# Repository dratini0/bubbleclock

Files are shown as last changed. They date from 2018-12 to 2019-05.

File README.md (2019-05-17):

# LED bubble display

This project is an ESP8266-based multiplexed driver for an 14 digit LED bubble display I have found somewhere.
It uses a separate battery charging and protection circuit, but has an internal LDO, more than capable enough to supply the display and the micro with sufficient power.

## Roadmap

- [x] Redesign with looser tolerances
- [x] Design and print case
- [x] Solder board
- [x] Finish MicroPython firmware, or develop native
  - [ ] Fix flickering issue

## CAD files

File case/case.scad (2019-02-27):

use <MCAD/regular_shapes.scad>
use <MCAD/boxes.scad>

// helper functions
function maxvector(vectors) = [for (index = [0:1:len(vectors[0]) - 1]) max([for (vector = vectors) vector[index]])];

function dotmul(a, b) = [for (index = [0:1:len(a) - 1]) a[index] * b[index]];

module box_between(a, b) {
    translate(a) cube(b - a);
}

// configuration
$fs = 0.2;
$fa = 5;

// unit: mm
mil = 0.0254;
wall = [1.2, 1.2, 1];
long_extension = 100;
cap_split = 20;

// BMS
bms_thickness = 1.1 + 0.2;
bms_length = 27.9 + 1;
bms_width = 17.2 + 0.5;
bms_parts = 2 + 1;
bms_back_parts = 0.5 + 0.5;
bms_usb_height = 3 + 1;
bms_usb_underhang = 0.3;
bms_usb_width = 8;
bms_porch = 0.5;
// ALSO USB PORT!
// FIND SPECS

// screen
screen_pcb_thickness = 1.6 + 0.2;
screen_pcb_length = 60.8 + 2;
screen_pcb_width = 18.4 + 1;
screen_pcb_end_porch = 1.5 - 0.2;
screen_pcb_top_porch = 1.6 - 0.2;
screen_bubble_thickness = 3.3 + 0.3;
screen_right_edge_to_last_connector_center = 4.9;
screen_bottom_edge_to_connector_center = 2.18 + 0.5;
// Lasercut a 60mm*14.5mm piece of acrylic 2mm thick
screen_window_thickness = 2 + 0.2;
screen_window_lip = 1;
screen_window_bottom_porch = 3.5 - 0.2;

// connector
connector_pitch = 100 * mil;
connector_pins = 22;
connector_length = connector_pitch * connector_pins + 1;
connector_screen_center_to_driver_face = 180 * mil;
// https://hu.mouser.com/datasheet/2/418/NG_CD_644694_E2-1257639.pdf
connector_driver_center_to_screen_face = 8.7 + 92 * mil / 2;
connector_width = 2.5 + 0.5;

// driver
driver_thickness = 1.6 + 0.3;
driver_length = 57.15 + 2;
driver_width = 22.86 + 1;
driver_programming_connector_height = 4.4 + 1;
driver_programming_connector_extension = 2.5;
driver_top_component_height = 2.3 + 0.8;
// https://datasheet.lcsc.com/szlcsc/Ai-Thinker-ESP-12F-ESP8266MOD_C82891.pdf
driver_bottom_component_height = 2.7;
// http://www.ti.com/lit/ds/symlink/sn74hc595.pdf
driver_front_porch = 0.6;
// protrusion for switch, maybe add lever?
driver_back_top_porch = -1;
driver_back_bottom_porch = 0.5;
driver_right_edge_to_last_connector_center = 1.9;
driver_front_edge_to_connector_center = 1.9 + 0.5;
driver_switch_hole_position = 3 - 1;
driver_switch_hole_length = 4 + 2;
driver_switch_hole_width = 2;

// battery (standard 18650)
battery_dia = 18 + 1;
battery_len = 65 + 5;

// screw hole
screw_hole_dia = 5 + 1; // M3
screw_nut_dia = 9.2 + 0.2;
screw_nut_height = 4;
screw_hole_pos = [screw_nut_dia / 2 * cos(30), 11, 0];

// sample
sample_height = 15;
sample_thickness = 3;

module battery(){
    translate([battery_dia / 2, battery_dia / 2])
    cylinder(h = battery_len, d = battery_dia);
}

battery = [battery_dia, battery_dia, battery_len];

//battery();

module driver() {
    translate([0, - driver_front_edge_to_connector_center, -driver_right_edge_to_last_connector_center]) {
        // PCB
        translate([-driver_thickness, 0, 0])
        cube([driver_thickness, driver_width, driver_length]);
        // front componets
        translate([0, driver_front_porch, -driver_programming_connector_extension])
        cube([driver_programming_connector_height, driver_width - driver_front_porch - driver_back_top_porch, driver_length + driver_programming_connector_extension]);
        // back components
        translate([- driver_thickness - driver_bottom_component_height, driver_front_porch, 0])
        cube([driver_bottom_component_height, driver_width - driver_front_porch - driver_back_bottom_porch, driver_length]);
        // switch cutout
        translate([0, driver_width - driver_back_top_porch, driver_switch_hole_position])
        cube([driver_switch_hole_width, long_extension, driver_switch_hole_length]);
    }
}

//driver();

module screen() {
    translate ([- screen_bottom_edge_to_connector_center, 0, - screen_right_edge_to_last_connector_center]) {
        // PCB
        translate([0, - screen_pcb_thickness, 0])
        cube([screen_pcb_width, screen_pcb_thickness, screen_pcb_length]);
        // Bubbles
        translate([0, - screen_pcb_thickness - screen_bubble_thickness, screen_pcb_end_porch])
        cube([screen_pcb_width - screen_pcb_top_porch, screen_bubble_thickness, screen_pcb_length - 2 * screen_pcb_end_porch]);
        // PMMA window
        translate([screen_window_bottom_porch, - screen_pcb_thickness - screen_bubble_thickness - screen_window_thickness, screen_pcb_end_porch])
        cube([screen_pcb_width - screen_pcb_top_porch - screen_window_bottom_porch, screen_window_thickness, screen_pcb_length - 2 * screen_pcb_end_porch]);
        // window cutout
        translate([screen_window_bottom_porch + screen_window_lip, - screen_pcb_thickness - screen_bubble_thickness - screen_window_thickness - long_extension, screen_pcb_end_porch])
        cube([screen_pcb_width - screen_pcb_top_porch - screen_window_bottom_porch - 2 * screen_window_lip, long_extension, screen_pcb_length - 2 * screen_pcb_end_porch]);
    }
}

//screen();

module connector() {
    translate([0, 0, - connector_pitch / 2]) {
        //driver side
        translate([0, connector_driver_center_to_screen_face - connector_width / 2, 0])
        cube([connector_screen_center_to_driver_face + connector_width / 2, connector_width, connector_length]);
        //screen side
        translate([connector_screen_center_to_driver_face - connector_width / 2, 0, 0])
        cube([connector_width, connector_driver_center_to_screen_face + connector_width / 2, connector_length]);
    }
}

module screen_driver_assembly() {
    translate([driver_thickness + driver_bottom_component_height, screen_pcb_thickness + screen_bubble_thickness + screen_window_thickness, max(driver_right_edge_to_last_connector_center + driver_programming_connector_extension, screen_right_edge_to_last_connector_center)]) {
        translate([0, connector_driver_center_to_screen_face, 0]) driver();
        translate([connector_screen_center_to_driver_face, 0, 0]) screen();
        connector();
    }
}

screen_driver_assembly_usable_area_1 = [
driver_thickness + driver_bottom_component_height + driver_programming_connector_height,
screen_pcb_thickness + screen_bubble_thickness + screen_window_thickness + connector_driver_center_to_screen_face + connector_width / 2,
0,
];

screen_driver_assembly_usable_area_2 = [
driver_thickness + driver_bottom_component_height + connector_screen_center_to_driver_face + connector_width / 2,
screen_pcb_thickness + screen_bubble_thickness + screen_window_thickness,
0,
];

screen_driver_assembly = [
screen_pcb_width - screen_bottom_edge_to_connector_center + connector_screen_center_to_driver_face + driver_thickness + driver_bottom_component_height,
driver_width - min(0, driver_back_bottom_porch, driver_back_top_porch) - driver_front_edge_to_connector_center + connector_driver_center_to_screen_face + screen_pcb_thickness + screen_bubble_thickness + screen_window_thickness,
max(driver_right_edge_to_last_connector_center + driver_programming_connector_extension, screen_right_edge_to_last_connector_center) +
max(driver_length - driver_right_edge_to_last_connector_center, screen_pcb_length - screen_right_edge_to_last_connector_center),
];

//screen_driver_assembly();

module bms() {
    translate([0, bms_back_parts, 0]) {
        // PCB
        cube([bms_width, bms_thickness, bms_length]);
        // back "parts"
        translate([bms_porch, - bms_back_parts, 0])
        cube([bms_width - 2 * bms_porch, bms_back_parts, bms_length]);
        // front parts
        translate([bms_porch, bms_thickness, 0])
        cube([bms_width - 2 * bms_porch, bms_parts, bms_length]);
        // USB port
        translate([(bms_width - bms_usb_width) / 2, bms_thickness, - long_extension])
        cube([bms_usb_width, bms_usb_height + bms_usb_underhang, long_extension + bms_length]);
    }
}

bms = 
[
bms_width,
bms_back_parts + bms_thickness + max(bms_usb_height, bms_parts),
bms_length,
];

//bms();

screen_driver_assembly_placement = wall;
bms_placement = screen_driver_assembly_placement + screen_driver_assembly_usable_area_2 + dotmul(wall, [1, 1, 0]);
// we don't have assert yet here
// which is stupid!
echo(bms_placement + bms);
echo(screen_driver_assembly_placement + screen_driver_assembly_usable_area_1);
echo((bms_placement + bms).y < (screen_driver_assembly_placement + screen_driver_assembly_usable_area_1).y);

battery_placement = screen_driver_assembly_placement + screen_driver_assembly_usable_area_1 + dotmul(wall, [1, 1, 0]);

totalboxsize = maxvector([
battery_placement + battery,
bms_placement + bms,
screen_driver_assembly_placement + screen_driver_assembly,
]) + wall;

echo(totalboxsize);

module screw(){
    // threaded rod
    cylinder(h = long_extension, d = screw_hole_dia);
    // nut
    rotate([0, 0, 90])
    translate([0, 0, totalboxsize.z - screw_nut_height])
    linear_extrude(long_extension)
    reg_polygon(6, screw_nut_dia / 2);
}
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

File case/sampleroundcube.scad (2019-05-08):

use <MCAD/boxes.scad>

$fs = 0.05;
$fa = 1;

// unit: mm
wall = [1.2, 1.2, 1];
intersection() {
    translate([5,5,5])
    roundedBox([10, 10, 10], wall.x);
    cube([10,10,2]);
}

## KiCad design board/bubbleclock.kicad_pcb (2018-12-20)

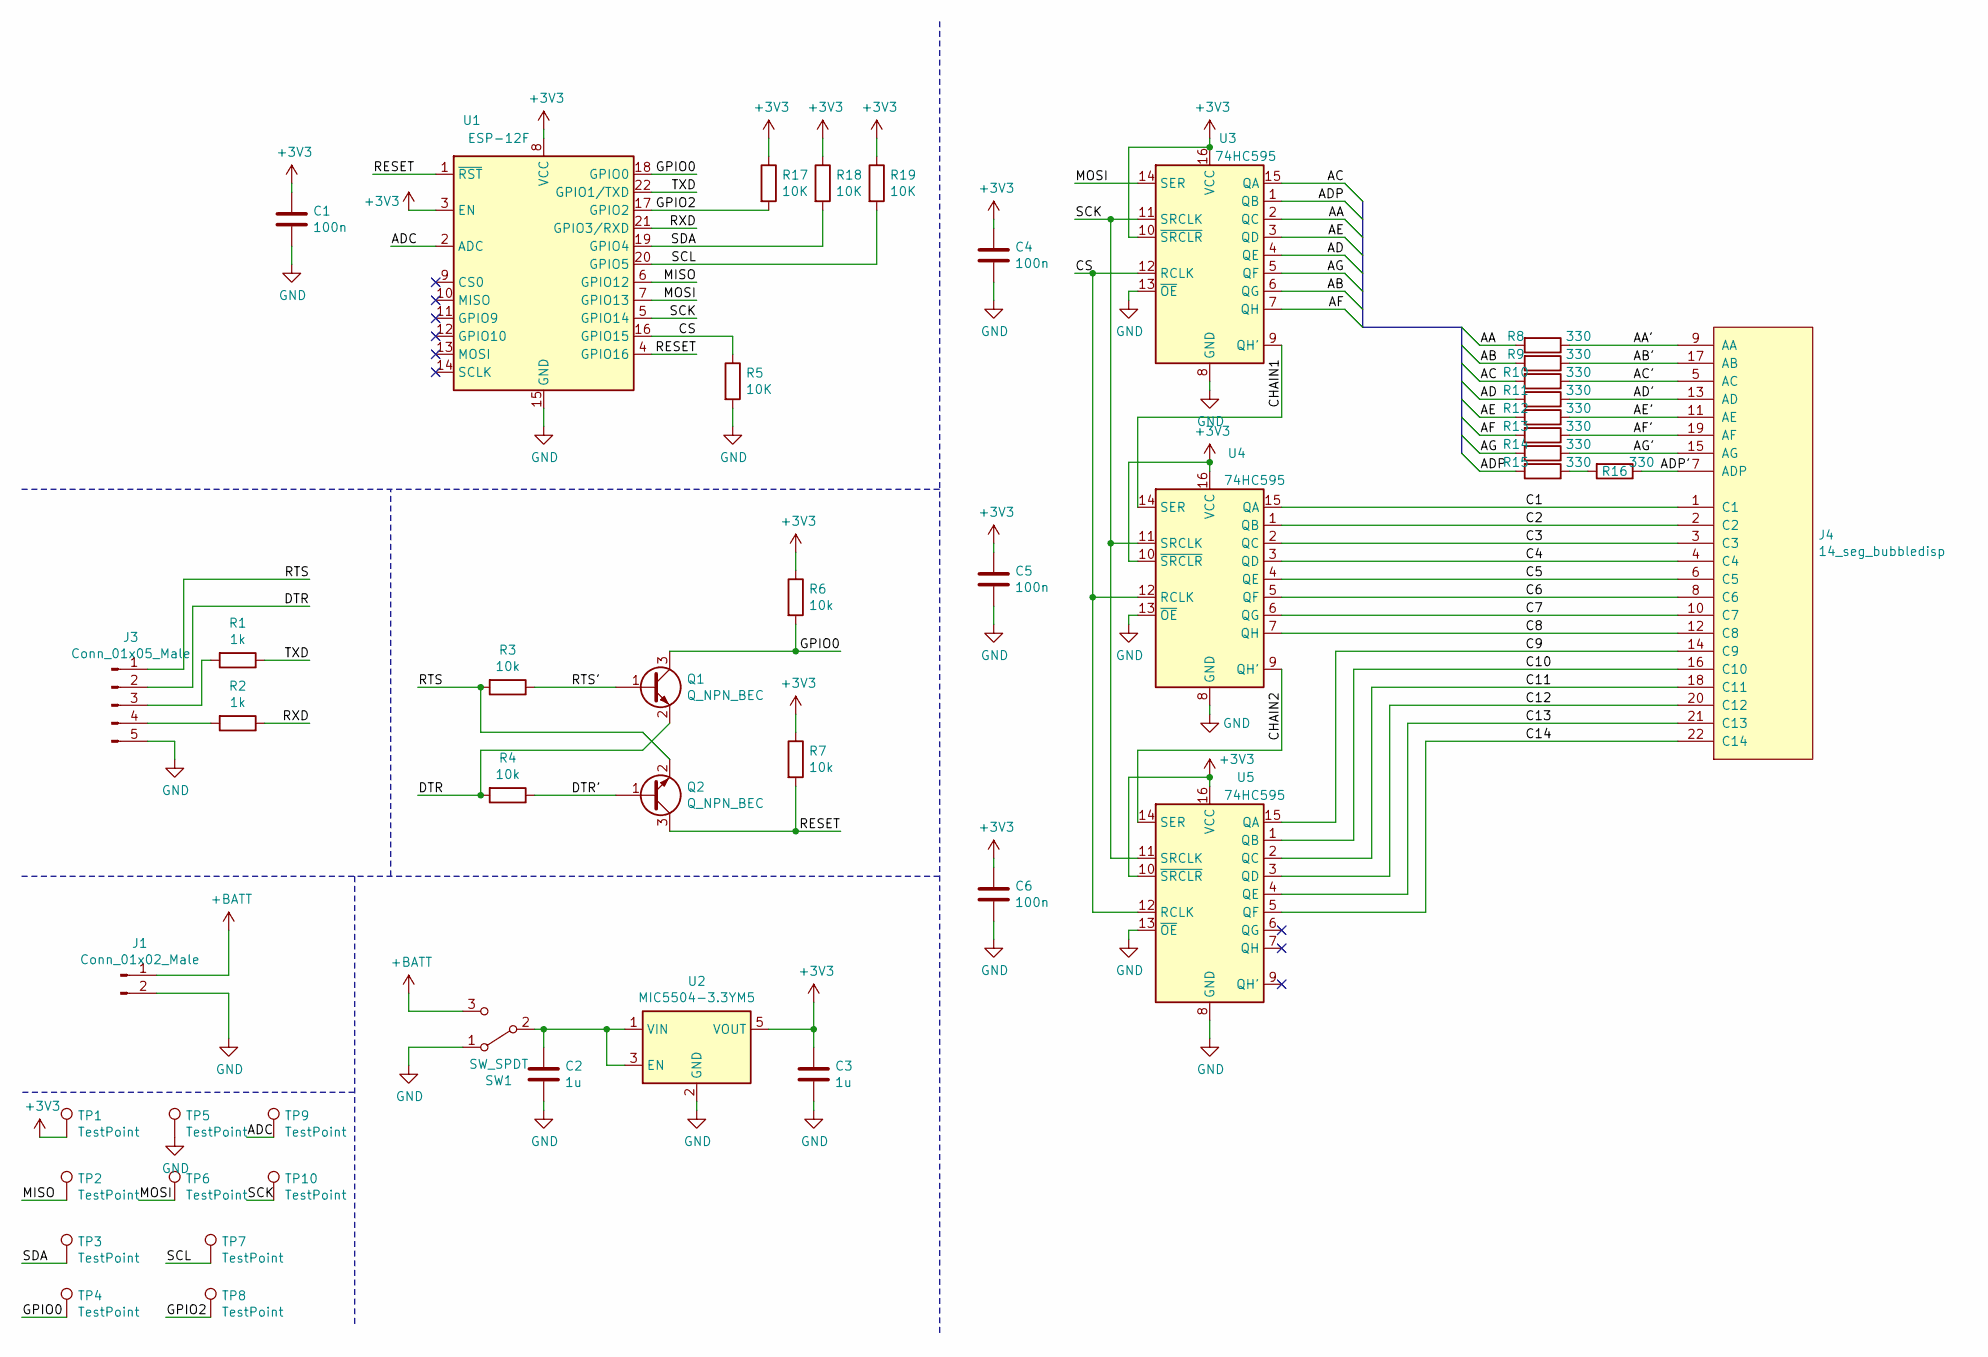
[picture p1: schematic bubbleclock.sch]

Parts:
C1, C4, C5, C6: 100n; C_0805_2012Metric_Pad1.15x1.40mm_HandSolder
C2, C3: 1u; C_0805_2012Metric_Pad1.15x1.40mm_HandSolder
J1: Conn_01x02_Male; PinHeader_1x02_P2.54mm_Vertical
J3: Conn_01x05_Male; PinHeader_1x05_P2.54mm_Horizontal
J4: 14_seg_bubbledisp; PinHeader_1x22_P2.54mm_Vertical
Q1, Q2: Q_NPN_BEC; SOT-23_Handsoldering
R1, R2: 1k; R_0805_2012Metric_Pad1.15x1.40mm_HandSolder
R3, R4, R6, R7: 10k; R_0805_2012Metric_Pad1.15x1.40mm_HandSolder
R5, R17, R18, R19: 10K; R_0805_2012Metric_Pad1.15x1.40mm_HandSolder
R8, R9, R10, R11, R12, R13, R14, R15, R16: 330; R_0805_2012Metric_Pad1.15x1.40mm_HandSolder
SW1: SW_SPDT; SW_SPDT_PCM12
TP1, TP2, TP3, TP4, TP5, TP6, TP7, TP8, TP9, TP10: TestPoint; TestPoint_Pad_2.5x2.5mm
U1: ESP-12F; ESP-12E
U2: MIC5504-3.3YM5; SOT-23-5_HandSoldering
U3, U4, U5: 74HC595; SOIC-16_3.9x9.9mm_P1.27mm

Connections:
+3V3: C1.1, C3.1, C4.1, C5.1, C6.1, R6.1, R7.1, R17.1, R18.1, R19.1, TP1.1, U1.3 (EN), U1.8 (VCC), U2.5 (VOUT), U3.10 (~SRCLR), U3.16 (VCC), U4.10 (~SRCLR), U4.16 (VCC), U5.10 (~SRCLR), U5.16 (VCC)
+BATT: J1.1, SW1.3 (C)
/AA: R8.2, U3.2 (QC)
/AA': J4.9 (AA), R8.1
/AB: R9.2, U3.6 (QG)
/AB': J4.17 (AB), R9.1
/AC: R10.2, U3.15 (QA)
/AC': J4.5 (AC), R10.1
/AD: R11.2, U3.4 (QE)
/AD': J4.13 (AD), R11.1
/ADC: TP9.1, U1.2 (ADC)
/ADP: R15.2, U3.1 (QB)
/ADP': J4.7 (ADP), R16.1
/AE: R12.2, U3.3 (QD)
/AE': J4.11 (AE), R12.1
/AF: R13.2, U3.7 (QH)
/AF': J4.19 (AF), R13.1
/AG: R14.2, U3.5 (QF)
/AG': J4.15 (AG), R14.1
/C1: J4.1 (C1), U4.15 (QA)
/C2: J4.2 (C2), U4.1 (QB)
/C3: J4.3 (C3), U4.2 (QC)
/C4: J4.4 (C4), U4.3 (QD)
/C5: J4.6 (C5), U4.4 (QE)
/C6: J4.8 (C6), U4.5 (QF)
/C7: J4.10 (C7), U4.6 (QG)
/C8: J4.12 (C8), U4.7 (QH)
/C9: J4.14 (C9), U5.15 (QA)
/C10: J4.16 (C10), U5.1 (QB)
/C11: J4.18 (C11), U5.2 (QC)
/C12: J4.20 (C12), U5.3 (QD)
/C13: J4.21 (C13), U5.4 (QE)
/C14: J4.22 (C14), U5.5 (QF)
/CHAIN1: U3.9 (QH'), U4.14 (SER)
/CHAIN2: U4.9 (QH'), U5.14 (SER)
/CS: R5.1, U1.16 (GPIO15), U3.12 (RCLK), U4.12 (RCLK), U5.12 (RCLK)
/DTR: J3.2, Q1.2 (E), R4.2
/DTR': Q2.1 (B), R4.1
/GPIO0: Q1.3 (C), R6.2, TP4.1, U1.18 (GPIO0)
/GPIO2: R17.2, TP8.1, U1.17 (GPIO2)
/MISO: TP2.1, U1.6 (GPIO12)
/MOSI: TP6.1, U1.7 (GPIO13), U3.14 (SER)
/RESET: Q2.3 (C), R7.2, U1.1 (~RST), U1.4 (GPIO16)
/RTS: J3.1, Q2.2 (E), R3.2
/RTS': Q1.1 (B), R3.1
/RXD: R2.1, U1.21 (GPIO3/RXD)
/SCK: TP10.1, U1.5 (GPIO14), U3.11 (SRCLK), U4.11 (SRCLK), U5.11 (SRCLK)
/SCL: R19.2, TP7.1, U1.20 (GPIO5)
/SDA: R18.2, TP3.1, U1.19 (GPIO4)
/TXD: R1.1, U1.22 (GPIO1/TXD)
GND: C1.2, C2.2, C3.2, C4.2, C5.2, C6.2, J1.2, J3.5, R5.2, SW1.1 (A), TP5.1, U1.15 (GND), U2.2 (GND), U3.8 (GND), U3.13 (~OE), U4.8 (GND), U4.13 (~OE), U5.8 (GND), U5.13 (~OE)
unnamed: C2.1, SW1.2 (B), U2.1 (VIN), U2.3 (EN)
unnamed: J3.3, R1.2
unnamed: J3.4, R2.2
unnamed: R15.1, R16.2

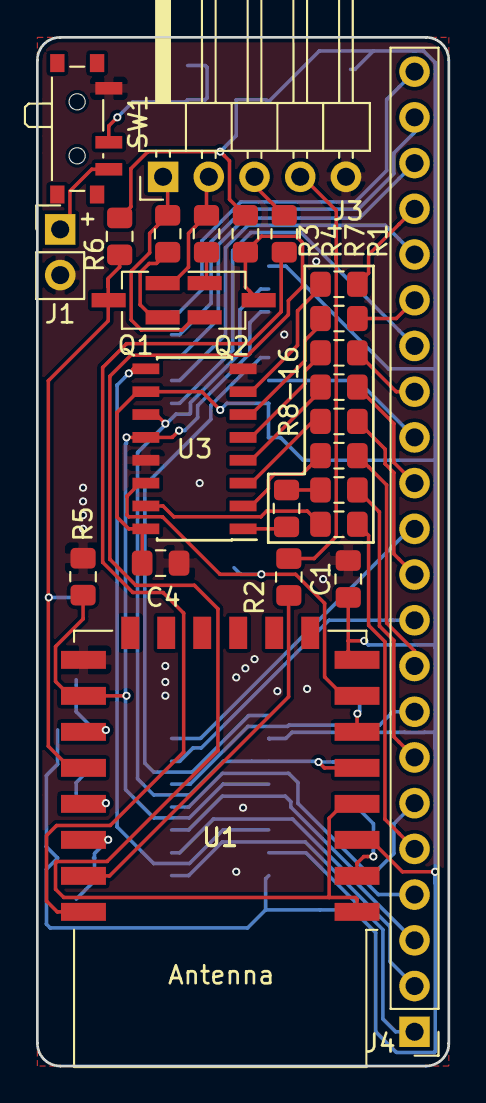
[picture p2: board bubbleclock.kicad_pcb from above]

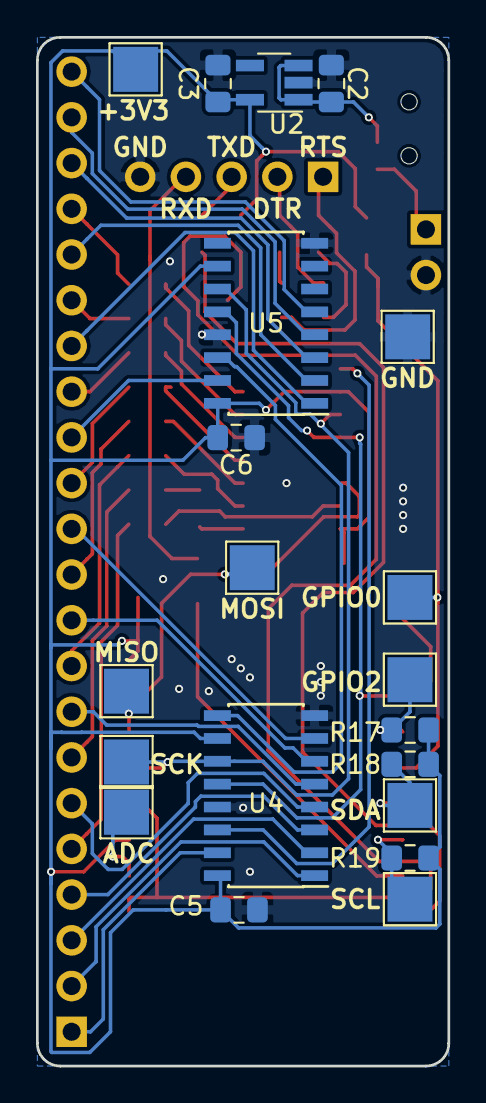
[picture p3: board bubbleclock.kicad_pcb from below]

Board: 2 copper layers, 22.9 x 57.2 mm, 46 parts (20 on the bottom side), 55 nets.

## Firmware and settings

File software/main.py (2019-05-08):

# -*- coding: utf-8 -*-

import machine
from alphabet import *
import utime
import micropython

CS = machine.Pin(15, machine.Pin.OUT)
spi = machine.SPI(1, baudrate=8000000, polarity=0, phase=0)
CS.on()
index = 0
data = bytearray([
    0xff, 0xfe, 0xff,
    0xff, 0xfd, 0xff,
    0xff, 0xfb, 0xff,
    0xff, 0xf7, 0xff,
    0xff, 0xef, 0xff,
    0xff, 0xdf, 0xff,
    0xff, 0xbf, 0xff,
    0xff, 0x7f, 0xff,
    0xfe, 0xff, 0xff,
    0xfd, 0xff, 0xff,
    0xfb, 0xff, 0xff,
    0xf7, 0xff, 0xff,
    0xef, 0xff, 0xff,
    0xdf, 0xff, 0xff,
])
LEN_DATA = len(data)
def cb(_):
    global index
    CS.off()
    spi.write(data[index:index+3])
    CS.on()
    index += 3
    if index >= LEN_DATA:
        index = 0

tim = machine.Timer(-1)
tim.init(period=1, mode=machine.Timer.PERIODIC, callback=cb)

def set_letter_raw(place, letter):
    data[place * 3 + 2] = letter

def update_raw(text):
    for i in range(14):
        if i < len(text):
            set_letter_raw(i, text[i])
        else:
            set_letter_raw(i, 0)

def prepare_text(text):
    result = bytearray(len(text))
    position = 0
    for letter in text:
        letter = letter.upper()
        if letter not in alphabet:
            letter = ' '
        if position > 0 and letter == '.':
            result[position - 1] |= alphabet[letter]
        else:
            result[position] = alphabet[letter]
            position += 1
    return bytes(result[0:position])

def update(text):
    update_raw(prepare_text(text))

def update_clock(_):
    update('{:014}'.format(utime.time()))

def schedule_update_clock(t):
    micropython.schedule(update_clock, t)

clocktimer = machine.Timer(-1)
clocktimer.init(period=1000, mode=machine.Timer.PERIODIC, callback=schedule_update_clock)
update_clock(0)

def stop():
    tim.deinit()
    CS.off()
    spi.write(b'\0\0\0')
    CS.on()
    clocktimer.deinit()

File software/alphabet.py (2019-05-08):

# -*- coding: utf-8 -*-

A = 1 << 2
B = 1 << 6
C = 1 << 0
D = 1 << 4
E = 1 << 3
F = 1 << 7
G = 1 << 5
DP = 1 << 1

alphabet = {
    ' ': 0,
    '0': A | B | C | D | E | F,
    '1': B | C,
    '2': A | B | D | E | G,
    '3': A | B | C | D | G,
    '4': B | C | F | G,
    '5': A | C | D | F | G,
    '6': A | C | D | E | F | G,
    '7': A | B | C,
    '8': A | B | C | D | E | F | G,
    '9': A | B | C | D | F | G,
    'A': A | B | C | E | F | G,
    'B': C | D | E | F | G,
    'C': A | D | E | F,
    'D': B | C | D | E | G,
    'E': A | D | E | F | G,
    'F': A | E | F | G,
    'G': A | C | D | E | F,
    'H': B | C | E | F | G,
    'I': E | F,
    'J': B | C | D,
    'K': E | F | G,
    'L': D | E | F,
    'M': A | C | E,
    'N': A | B | C | E | F,
    'O': A | B | C | D | E | F,
    'P': A | B | E | F | G,
    'Q': A | B | C | F | G,
    'R': A | E | F,
    'S': A | C | D | F | G,
    'T': D | E | F | F | G,
    'U': B | C | D | E | F,
    'V': C | D | E,
    'W': B | D | F,
    'X': B | C | E | F,
    'Y': B | E | F | G,
    'Z': A | B | D | E | G,
    '_': D,
    '\'': B,
    '-': G,
    '.': DP,
    '!': B | C | DP,
    '"': B | F,
    "(": A | D | E | F,
    ")": A | B | C | D,
    "[": A | D | E | F,
    "]": A | B | C | D,
    "{": A | D | E | F | G,
    "}": A | B | C | D | G,
    "<": D | E | G,
    ">": C | D | G,
    "/": B | E | G,
    "\\": C | F | G,
    "|": B | C,
}

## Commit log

2018-12-14 Initial commit
    At this point, I have a board routed, but it is ugly and hard to get
    manufactured.
    [bubbleclock.kicad_pcb, bubbleclock.sch]
2018-12-14 schematic improvements. Board not updated, is broken.
    I pulled GPIO15 high instead of low. OOPS!
    [bubbleclock.sch]
2018-12-15 Redesigned with looser tolerances
    Don't torture the boardhouse, plus implementing schematic fixes
    Fixes:
    1. Pull GPIO0 low instead of high
    2. Short regulator enable to VIN
    [bubbleclock.kicad_pcb, bubbleclock.sch]
2018-12-15 Set JLCPCB plotting prefs, move misplaced label
    [bubbleclock.kicad_pcb]
2018-12-19 Minimal tweaks, send to fab!
    * Move programming connector down
    * Add some sizes
    [bubbleclock.kicad_pcb]
2018-12-20 More messing with dimensions
    [bubbleclock.kicad_pcb]
2018-12-20 First layout of parts in case
    [case.scad]
2018-12-21 Draw the rest of the owl... case
    [case.scad]
2019-02-14 Add Gerbers and STL to .gitignore
2019-02-14 Change screw to M5x70
    [case.scad]
2019-02-15 improve tolerances
    [case.scad]
2019-02-15 Enlarge wiring compartment, remove BMS retention
    [case.scad]
2019-02-15 add a sample, separate meshess
    Ugh, wish we could export multiple meshes from openscad
    [case.scad]
2019-02-27 Fully round corners + note window size
    The bottom edges will get squashed, but it will still be smoother
    [case.scad]
2019-05-08 Ignore exported .stl files
2019-05-08 Add a test object
    (it turned out OK)
    [sampleroundcube.scad]
2019-05-08 Prototype software (too much flicker)
    I think the flicker is inherent from the RTOS on the ESP8266. So in the
    new design, we will add a 328p
    [alphabet.py, main.py]
2019-05-08 Move board designs to separate folder
    [bubbleclock.kicad_pcb, bubbleclock.sch]
